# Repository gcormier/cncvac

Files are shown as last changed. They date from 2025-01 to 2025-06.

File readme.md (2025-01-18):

# cncvac
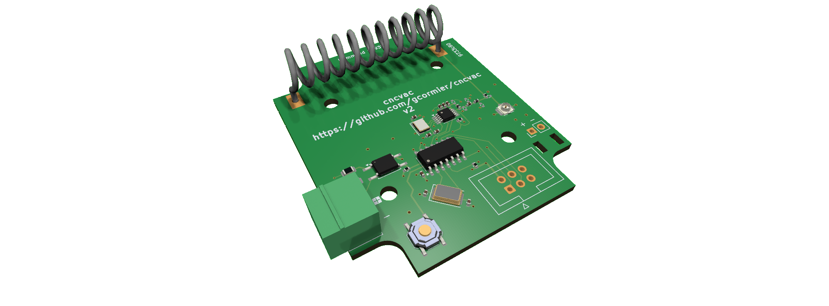
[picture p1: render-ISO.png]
Rendered ISO Image


This is a 433MHz ASK/FSK transmitter controlled by an ATTINY841.

It runs off regular AA/AAA batteries and can be used to control various devices like garage doors, gates, etc. The intent was to have it control my dust collection system in the shop which is using the iVac Pro system. The iVac Pro system is a great system but it is expensive and I wanted to have a cheaper alternative to control it, and the company did not offer a remote control that could be triggered from a logic signal. (They now sell one)

It has an opto-isolated input controlled by a 5-24V logic signal.

### Case
This fits in a [Hammond 1593P case](https://www.digikey.ca/en/products/detail/hammond-manufacturing/1593PBK/270098) and can use their [battery holder](https://www.digikey.ca/en/products/detail/hammond-manufacturing/BH3AAAW/3869833) as well.

### Power Consumption
#### Transmitting
1mV = 1uA
1-3mA while transmitting

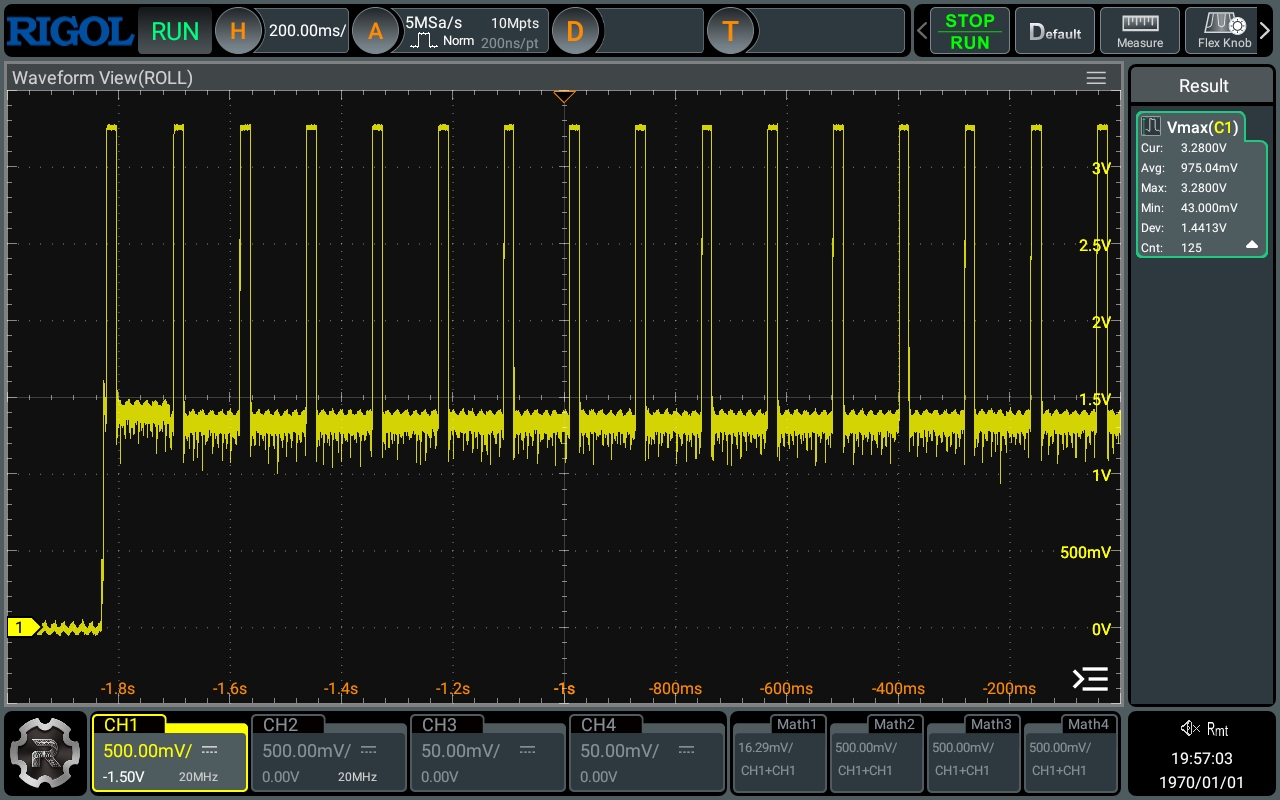
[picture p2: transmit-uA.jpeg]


#### Sleep/Idle
1mV = 1nA
Better than 1.2uA while sleeping
Based on the average capacity of two AA NiMH batteries, 2000mAh, this should last almost 200 years.
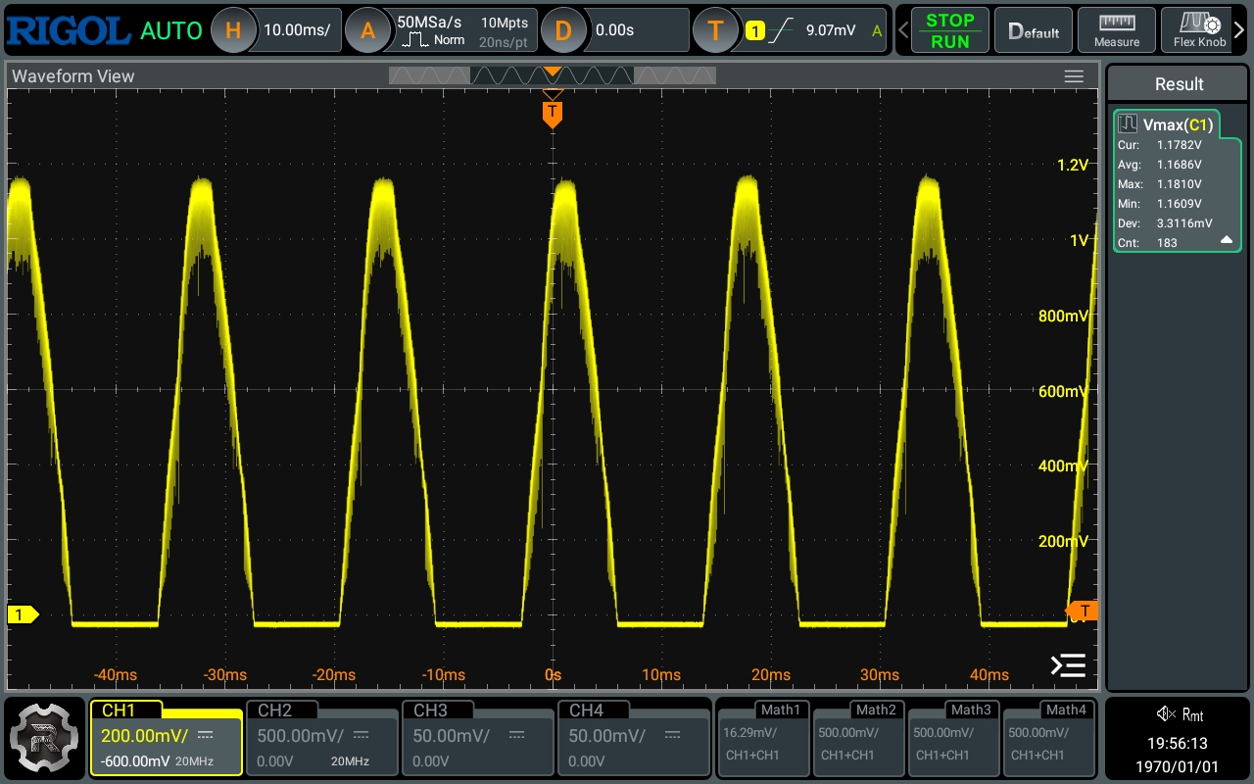
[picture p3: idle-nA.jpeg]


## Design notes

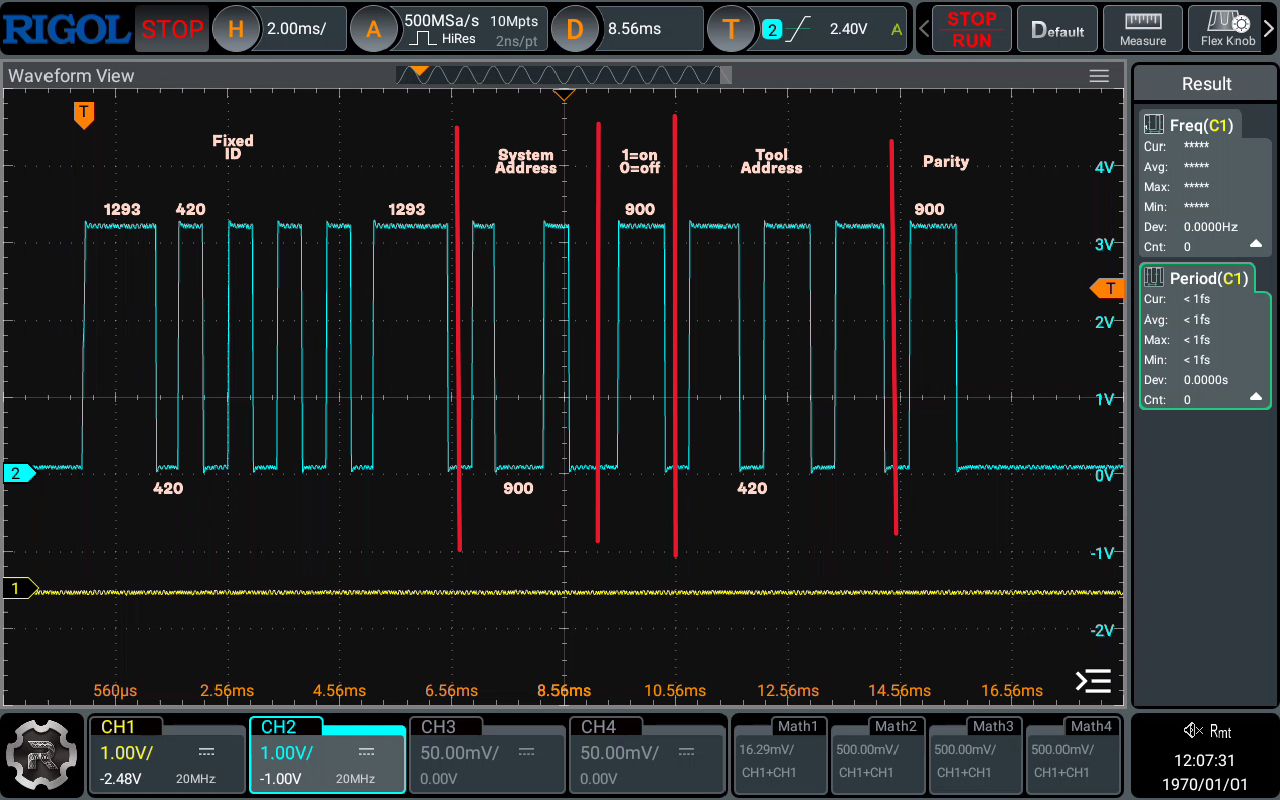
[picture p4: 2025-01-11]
code/captures/on_remote.png

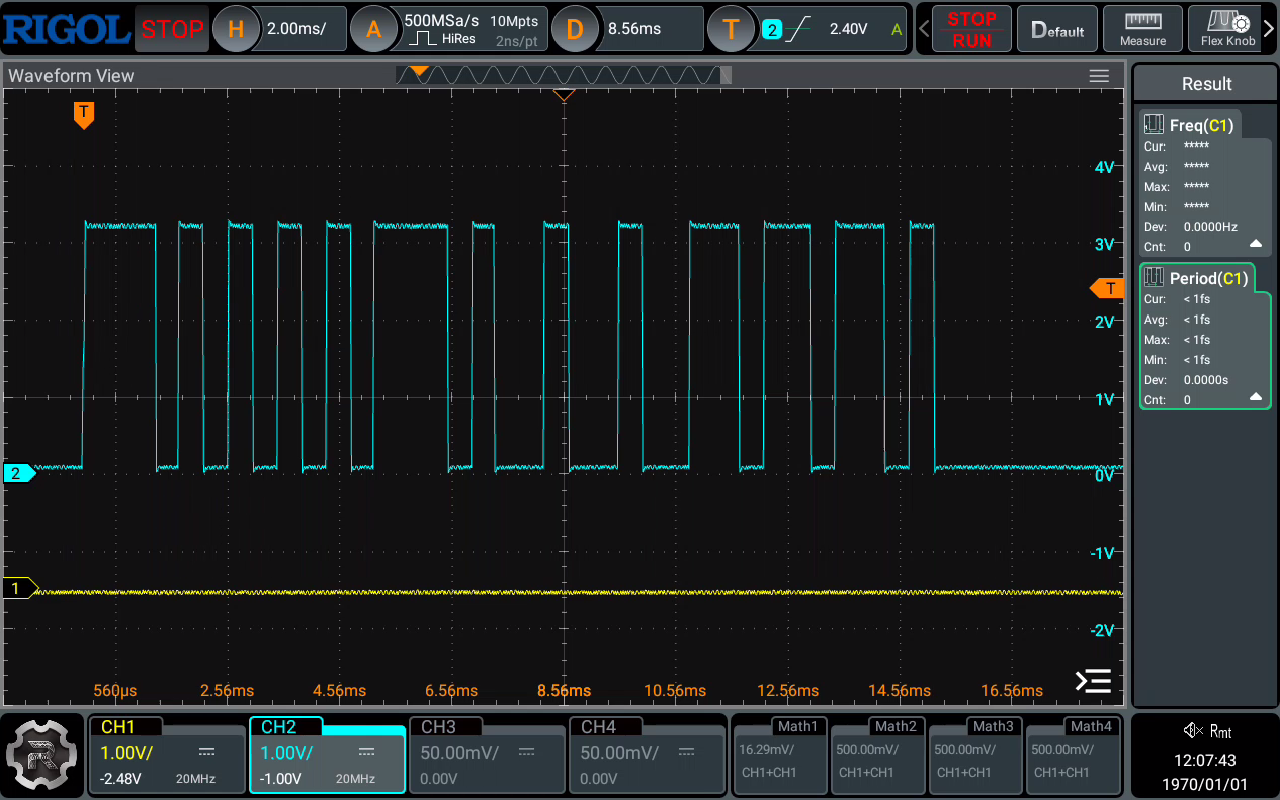
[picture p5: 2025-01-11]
code/captures/off_remote.png

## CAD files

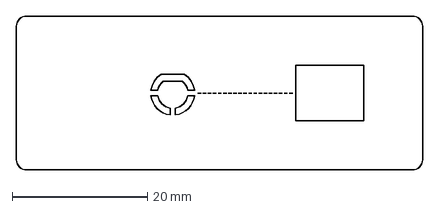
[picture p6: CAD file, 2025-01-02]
pcb/enclosurepanel/frontplate.dxf
60.0 x 22.7 mm

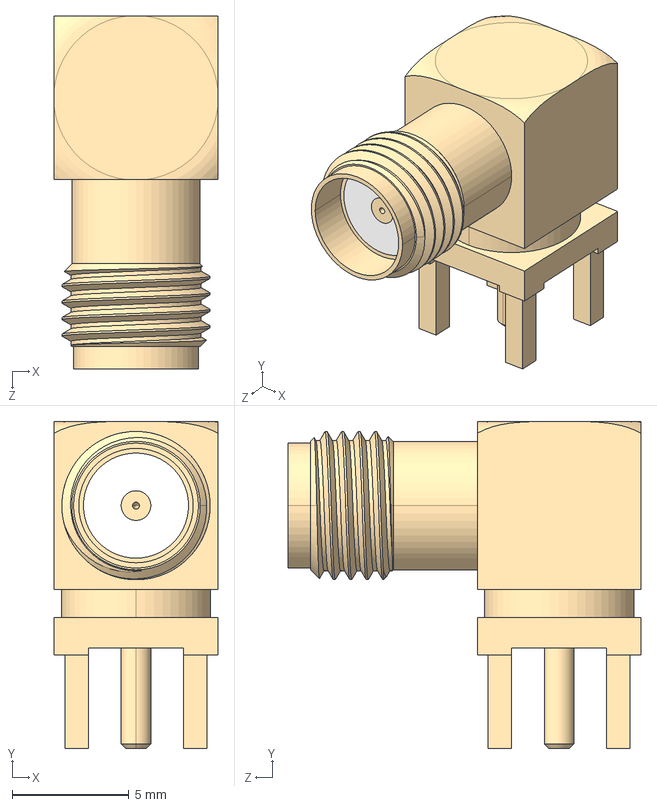
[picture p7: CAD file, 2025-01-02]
pcb/RFPC-SMA27.STEP
7.00 x 14.0 x 15.1 mm

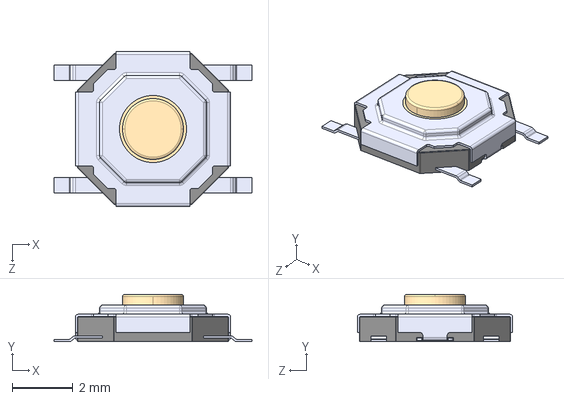
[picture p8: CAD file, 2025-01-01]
pcb/TS-1187A.STEP
6.50 x 1.55 x 5.10 mm

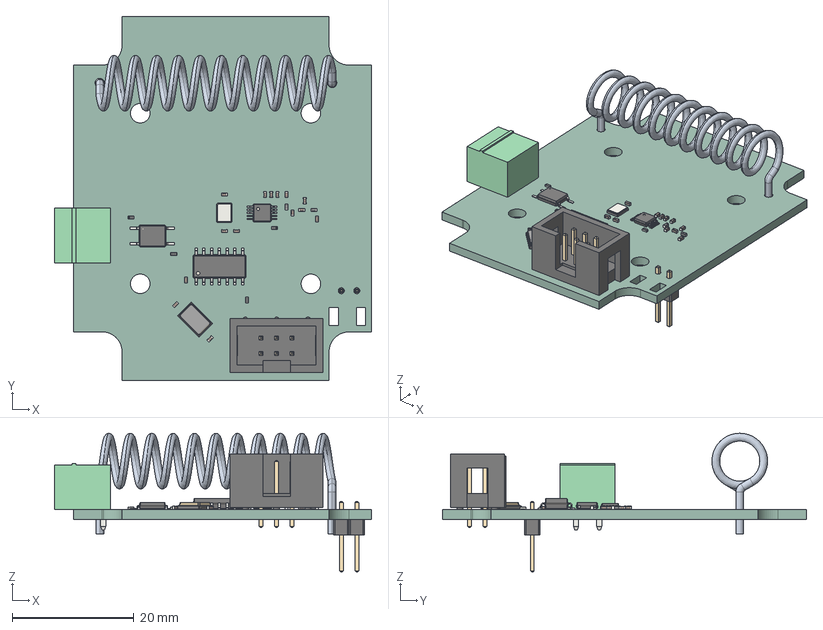
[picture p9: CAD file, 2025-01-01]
PCB/cncvac.step
52.0 x 59.7 x 22.7 mm
C_0402_1005Metric x 14
L_0402_1005Metric x 2
MSOP_10_3x3mm_P05mm
R_0402_1005Metric x 4
Crystal_SMD_3225-4Pin_3.2x2.5mm
Crystal_SMD_5032-2Pin_5.0x3.2mm
C-ANT-433-HETH
IDC_Header_2x03_P254mm_Vertical
MC_01x02_G_3_81mm
SO_4_44x36mm_P254mm
SOIC_14_39x87mm_P127mm
PinHeader_1x02_P254mm_Vertical
cncvac_PCB

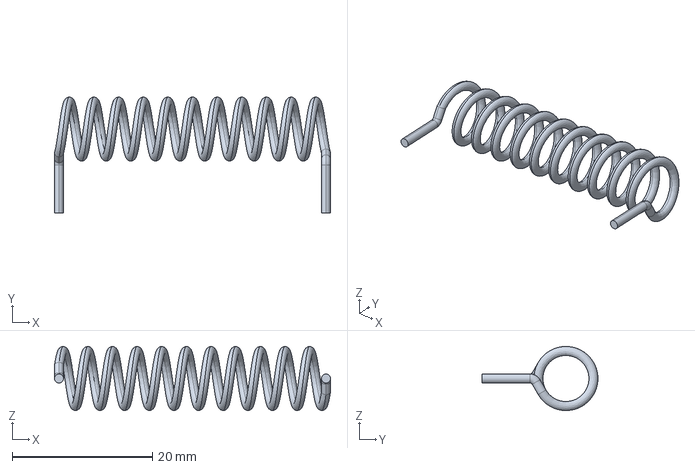
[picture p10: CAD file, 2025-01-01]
pcb/c-ant-433-heth-b-3d.stp
39.4 x 16.5 x 9.14 mm

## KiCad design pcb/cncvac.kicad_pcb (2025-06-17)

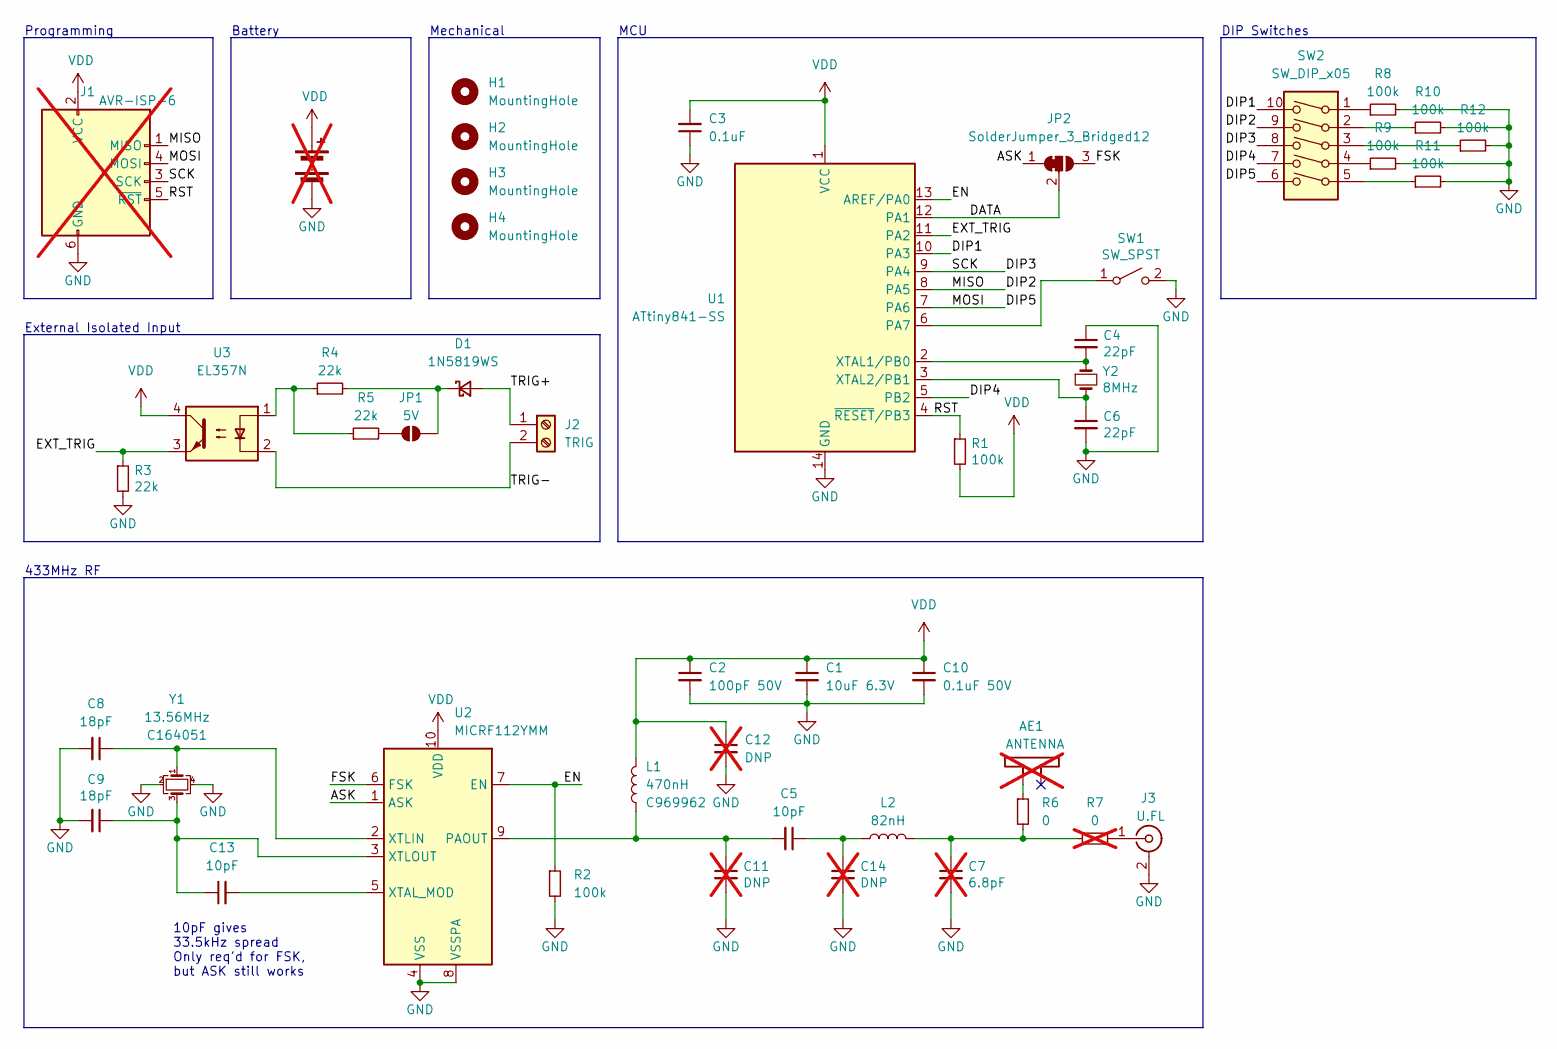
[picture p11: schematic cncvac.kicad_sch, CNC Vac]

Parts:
AE1: ANTENNA; ANT-433-HETH; not fitted
BT1: Battery; PinHeader_1x02_P2.54mm_Vertical; not fitted
C1: 10uF 6.3V; C_0402_1005Metric; LCSC C15525
C2: 100pF 50V; C_0402_1005Metric; LCSC C1546
C3: 0.1uF; C_0402_1005Metric; LCSC C307331
C4, C6: 22pF; C_0402_1005Metric; LCSC C1555
C5, C13: 10pF; C_0402_1005Metric; LCSC C32949
C7: 6.8pF; C_0402_1005Metric; not fitted
C8, C9: 18pF; C_0402_1005Metric; LCSC C1549
C10: 0.1uF 50V; C_0402_1005Metric; LCSC C307331
C11, C12, C14: DNP; C_0402_1005Metric; not fitted
D1: 1N5819WS; D_SOD-323; LCSC C191023
H1, H2, H3, H4: MountingHole; MountingHole_3.2mm_M3
J1: AVR-ISP-6; IDC-Header_2x03_P2.54mm_Vertical; not fitted
J2: TRIG; PhoenixContact_MC_1,5_2-G-3.81_1x02_P3.81mm_Horizontal; LCSC C8387
J3: U.FL; U.FL_Hirose_U.FL-R-SMT-1_Vertical; LCSC C5137195
JP1: 5V; SolderJumper-2_P1.3mm_Open_RoundedPad1.0x1.5mm
JP2: SolderJumper_3_Bridged12; SolderJumper-3_P1.3mm_Bridged12_RoundedPad1.0x1.5mm_NumberL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
L1: 470nH; L_0402_1005Metric; LCSC C969962
L2: 82nH; L_0402_1005Metric; LCSC C275301
R1, R2, R8, R9, R10, R11, R12: 100k; R_0402_1005Metric; LCSC C25741
R3, R4, R5: 22k; R_0805_2012Metric; LCSC C17560
R6: 0; R_0402_1005Metric; LCSC C17168
R7: 0; R_0402_1005Metric; LCSC C17168; not fitted
SW1: SW_SPST; SW_Push_1P1T_XKB_TS-1187A; LCSC C318884
SW2: SW_DIP_x05; SW_DIP_SPSTx05_Slide_9.78x14.88mm_W7.62mm_P2.54mm; LCSC C129061
U1: ATtiny841-SS; SOIC-14_3.9x8.7mm_P1.27mm; LCSC C614879
U2: MICRF112YMM; MSOP-10_3x3mm_P0.5mm; LCSC C481379
U3: EL357N; SO-4_4.4x3.6mm_P2.54mm; LCSC C42381015
Y1: 13.56MHz; Crystal_SMD_3225-4Pin_3.2x2.5mm; LCSC C164051
Y2: 8MHz; Crystal_SMD_5032-2Pin_5.0x3.2mm; LCSC C115962

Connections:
/ASK: JP2.1 (A), U2.1 (ASK)
/DATA: JP2.2 (C), U1.12 (PA1)
/DIP1: SW2.10, U1.10 (PA3)
/DIP2: J1.1 (MISO), SW2.9, U1.8 (PA5)
/DIP3: J1.3 (SCK), SW2.8, U1.9 (PA4)
/DIP4: SW2.7, U1.5 (PB2)
/DIP5: J1.4 (MOSI), SW2.6, U1.7 (PA6)
/EN: R2.1, U1.13 (AREF/PA0), U2.7 (EN)
/EXT_TRIG: R3.1, U1.11 (PA2), U3.3
/FSK: JP2.3 (B), U2.6 (FSK)
/RST: J1.5 (~RST), R1.1, U1.4 (~RESET/PB3)
/TRIG+: D1.2 (A), J2.1
/TRIG-: J2.2, U3.2
GND: BT1.2 (-), C1.2, C2.2, C3.1, C4.1, C6.2, C7.2, C8.2, C9.2, C10.2, C11.2, C12.2, C14.2, J1.6 (GND), J3.2 (Ext), R2.2, R3.2, R8.2, R9.2, R10.2, R11.2, R12.2, SW1.2 (B), U1.14 (GND), U2.4 (VSS), U2.8 (VSSPA), Y1.2, Y1.4
unnamed: AE1.2, R6.1
unnamed: C7.1, L2.2, R6.2, R7.1
unnamed: C5.1, C14.1, L2.1
unnamed: D1.1 (K), JP1.2 (B), R4.2
unnamed: J3.1 (In), R7.2
unnamed: JP1.1 (A), R5.2
unnamed: R4.1, R5.1, U3.1
unnamed: R8.1, SW2.1
unnamed: R9.1, SW2.4
unnamed: R10.1, SW2.2
unnamed: R11.1, SW2.5
unnamed: R12.1, SW2.3
unnamed: SW1.1 (A), U1.6 (PA7)
unnamed: C4.2, U1.2 (XTAL1/PB0), Y2.1
unnamed: C6.1, U1.3 (XTAL2/PB1), Y2.2
unnamed: C5.2, C11.1, L1.1, U2.9 (PAOUT)
unnamed: C13.2, U2.5 (XTAL_MOD)
unnamed: C8.1, U2.2 (XTLIN), Y1.1
unnamed: C9.1, C13.1, U2.3 (XTLOUT), Y1.3
VDD: BT1.1 (+), C1.1, C2.1, C3.2, C10.1, C12.1, J1.2 (VCC), L1.2, R1.2, U1.1 (VCC), U2.10 (VDD), U3.4

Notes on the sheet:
MCU
10pF gives 33.5kHz spread Only req'd for FSK, but ASK still works
Mechanical
External Isolated Input
Programming
Battery
433MHz RF
DIP Switches

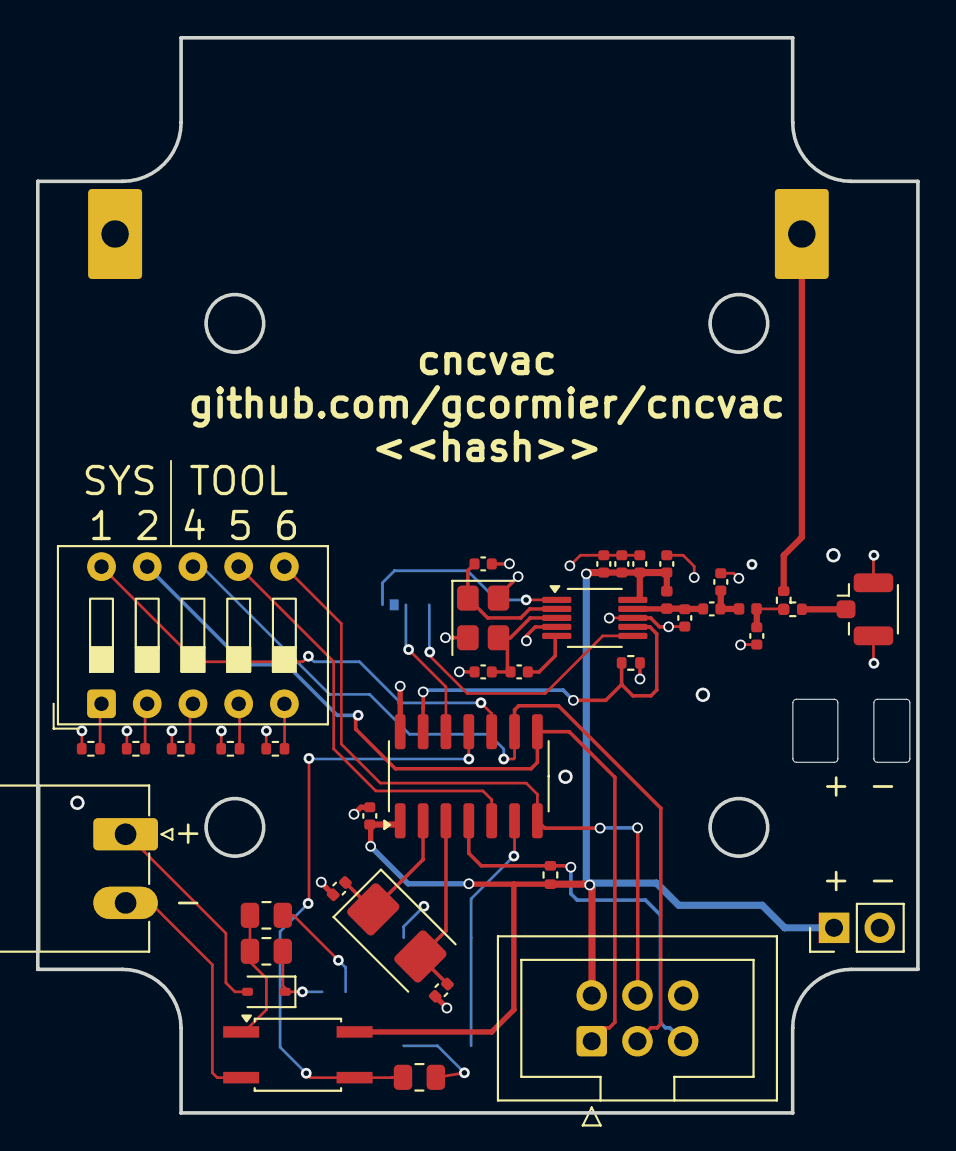
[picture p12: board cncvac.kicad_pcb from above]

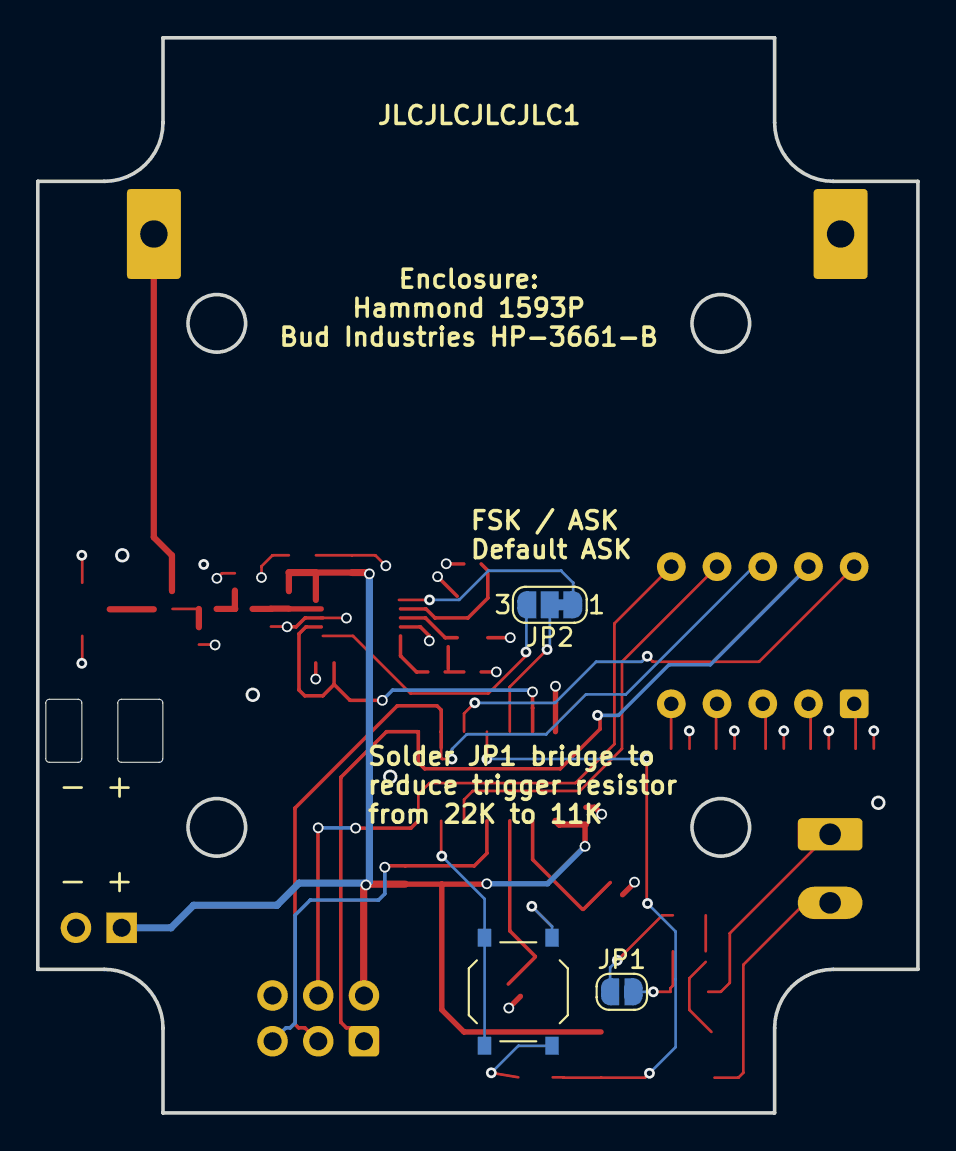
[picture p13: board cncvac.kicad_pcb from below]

Board: 4 copper layers, 48.9 x 59.7 mm, 47 parts (3 on the bottom side), 34 nets.

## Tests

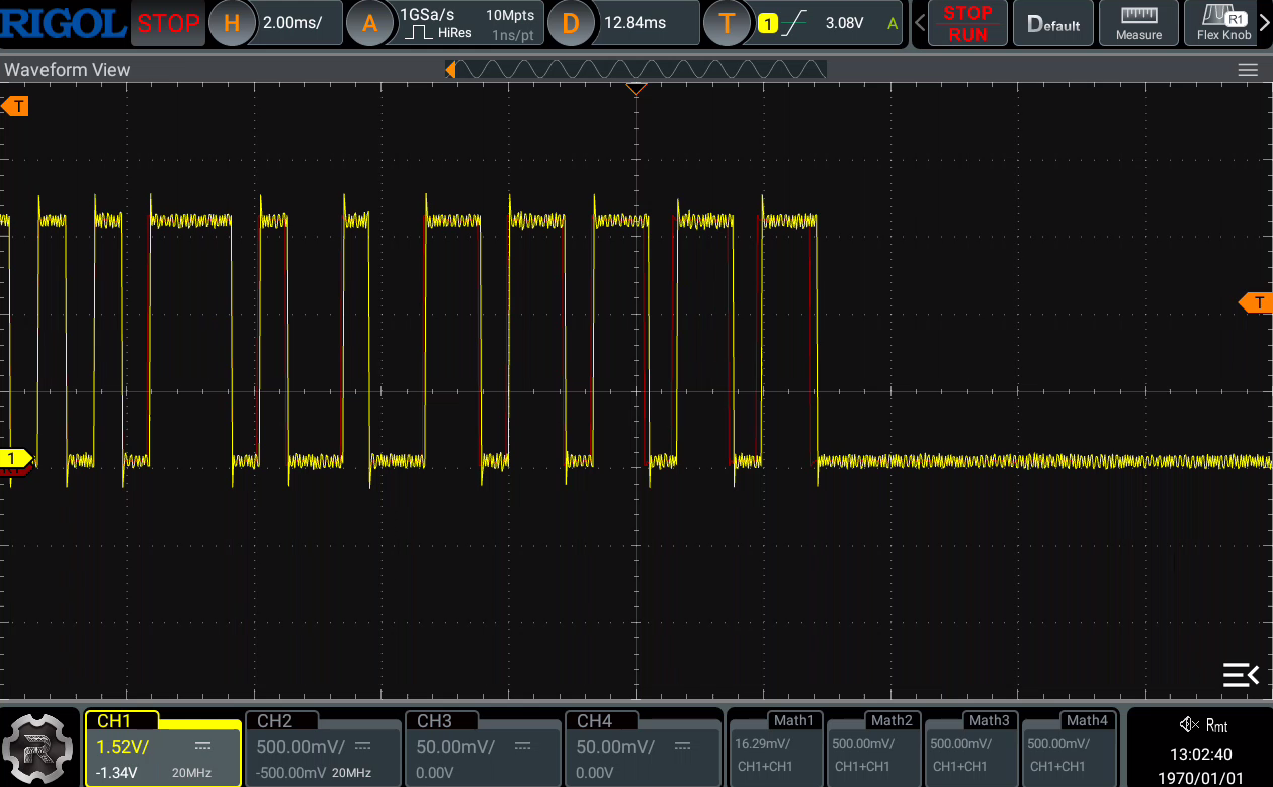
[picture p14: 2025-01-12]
code/captures/tuning.png

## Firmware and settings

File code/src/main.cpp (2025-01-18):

#include <avr/wdt.h>
#include <avr/power.h>
#include <avr/sleep.h>
#include <Arduino.h>
#include "cncvac.h"

///// Pinout https://github.com/SpenceKonde/ATTinyCore/blob/v2.0.0-devThis-is-the-head-submit-PRs-against-this/avr/extras/Pinout_x41.jpg
// Misery.
// PA0 or PORTA0 is defined by shitty platformio Atmel libraries and is broken
// A8 is defined by tinyavr and uses the clockwise/counterclockwise mapping. but it seems to break after a bit.
// Use raw numbers and test each output to make sure it works.

#define PIN_EN 0     // PA0, Pin 13, Arduino 10
#define PIN_FSK 1  // PA1, Pin 12, Arduino 9
#define PIN_ASK 2    // PA2, Pin 11, Arduino 8
#define PIN_BUTTON 7 // PA7, Pin 6, PCINT7
#define PIN_EXT_TRIG 3
#define PIN_MISC 8


#define ENHIGH (bitSet(PORTA, PIN_EN))
#define ENLOW (bitClear(PORTA, PIN_EN))

#define ASKHIGH (bitSet(PORTA, PIN_ASK))
#define ASKLOW (bitClear(PORTA, PIN_ASK))

#define FSKHIGH (bitSet(PORTA, PIN_FSK))
#define FSKLOW (bitClear(PORTA, PIN_FSK))

#define PACKET_DELAY 100 // Milliseconds inter-packet period

#define SHORTPACKETUS 410  // Short packet duration in uS
#define LONGPACKETUS 860   // Long packet duration in uS
#define TOTALPACKETUS 1250 // Total packet duration in uS for fix-bit width PWM

#define WEIRDLONGPACKETUS 1220 // Fixed preamble duration in uS
#define WEIRDSHORTPACKETUS 820 // Longer lows during system address
#define BREAKPACKETUS 2000     // Break between packets in uS
#define TWEAK 23               // Typically this will be your period (eg 50kHz interrupt, 20uS)
                               // but you can fine tune as needed

#define PACKET_RETRANSMIT 12 // How many times to resend the same packet?
#define PACKET_SIZE 13       // We only actually want 13 bits here

/*
             xxxx xx98 7654 3210
Bit position 1234 5678 1234 5678
             IIII IISS CTTT P000
*/

#define BIT_SYS1 9
#define BIT_SYS0 8
#define BIT_ONOFF 7
#define BIT_TOOL2 6
#define BIT_TOOL1 5
#define BIT_TOOL0 4
#define BIT_PARITY 3
#define FIXED 33792 // This is the fixed preamble. Do not change.

// This is where you define your on/off packet. You really need to only change the TOOL bits and the SYS bits.
// Even number of 1's? Set the bit parity flag.
const unsigned short onPacket = FIXED | (1 << BIT_ONOFF) | (1 << BIT_TOOL2) | (1 << BIT_TOOL1) | (1 << BIT_TOOL0) | (1 << BIT_PARITY);
const unsigned short offPacket = FIXED | (1 << BIT_TOOL2) | (1 << BIT_TOOL1) | (1 << BIT_TOOL0);

volatile unsigned short currentPacket = onPacket;
volatile unsigned int currentBit; // which bit in that packet is next

volatile bool transmitting = false; // indicates if transmitting a packet

volatile unsigned int wakeupReason = 0; // 1 = button, 2 = aux

volatile unsigned int tickCounter = 0; // count the number of interrupts, so we can determine how long to pulse for
volatile unsigned int sendLow = 0;     // Tell us to send the low signal
volatile unsigned int transmitCount;   // Countdown our transmit resends
volatile unsigned int previousBit = 0;

// setup functions

void calculateParity(unsigned short data)
{
  bool parityVal = false;
  for (int bit = 0; bit < 12; bit++)
  {
    // Calculate the parity of the first 12 bits in data, and store it in the 13th bit
    if (data & (1 << bit))
      parityVal = !parityVal;
  }
  data |= parityVal << 12;
}

// 50khz Interrupt for an 4MHz clock
// 50khz = 20uS
void setupInterrupt4()
{
  noInterrupts();
  // Clear registers
  TCCR1A = 0;
  TCCR1B = 0;
  TCNT1 = 0;

  OCR1A = 79;

  // CTC
  TCCR1B |= (1 << WGM12);

  // Prescaler 1
  TCCR1B |= (1 << CS00);

  // Output Compare Match A Interrupt Enable
  TIMSK1 |= (1 << OCIE1A);

  // button interrupt
  PCMSK0 |= (1 << PIN_BUTTON);

  // Opto interrupt
  PCMSK0 |= (1 << PIN_EXT_TRIG);
  GIMSK |= (1 << PCIE0);

  interrupts();
}

// 10khz Interrupt for an 8MHz clock
void setupInterrupt8()
{
  noInterrupts();
  // Clear registers
  TCCR1A = 0;
  TCCR1B = 0;
  TCNT1 = 0;

  // 10000 Hz (8000000/((99+1)*8))
  OCR1A = 99;
  // CTC
  TCCR1B |= (1 << WGM12);
  // Prescaler 8
  TCCR1B |= (1 << CS11);
  // Output Compare Match A Interrupt Enable
  TIMSK1 |= (1 << OCIE1A);

  // button interrupt
  PCMSK0 |= (1 << PIN_BUTTON);
  // Opto interrupt
  PCMSK0 |= (1 << PIN_EXT_TRIG);
  GIMSK |= (1 << PCIE0);

  interrupts();
}

// 10khz Interrupt for a 16MHz clock
void setupInterrupt16()
{
  noInterrupts();
  // Clear registers
  TCCR1A = 0;
  TCCR1B = 0;
  TCNT1 = 0;

  // 10000 Hz (16000000/((24+1)*64))
  OCR1A = 24;
  // CTC
  TCCR1B |= (1 << WGM12);
  // Prescaler 64
  TCCR1B |= (1 << CS11) | (1 << CS10);
  // Output Compare Match A Interrupt Enable
  TIMSK1 |= (1 << OCIE1A);

  // button interrupt
  PCMSK0 |= (1 << PIN_BUTTON);
  // Opto interrupt
  PCMSK0 |= (1 << PIN_EXT_TRIG);
  GIMSK |= (1 << PCIE0);

  interrupts();
}

void setup()
{
  // We have an 8MHz, and we have CKDIV8 fuse set, so we are running at 1MHz
  // This is to allow a safe startup with unknown power conditions. Then, we immediately
  // switch the scaler to 4MHz for a bit better performance, but we can still operate
  // down to 1.8V (datasheet page 238)
  cli();
  CLKPR = (1 << CLKPS0); // Set prescaler to divide by 2 (8 MHz / 2 = 4 MHz)
  sei();                 // Re-enable interrupts
  for (byte i = 0; i < 13; i++)
    pinMode(i, INPUT);

  // disable ADC + other stuff that uses power
  ADCSRA = 0;
  power_spi_disable();
  power_usart0_disable();
  power_usart1_disable();
  power_timer2_disable();
  power_twi_disable();
  // find more in power.h

  pinMode(PIN_EN, OUTPUT);
  pinMode(PIN_FSK, OUTPUT);
  pinMode(PIN_ASK, OUTPUT);
  pinMode(PIN_BUTTON, INPUT_PULLUP);
  pinMode(PIN_EXT_TRIG, INPUT);

#if F_CPU == 16000000L
  setupInterrupt16();
#elif F_CPU == 8000000L
  setupInterrupt8();
#elif F_CPU == 4000000L
  setupInterrupt4();
#else
#error Cannot set interrupt based on current clock frequency!
#endif
  disableTX();
}

// runtime functions

ISR(TIMER1_COMPA_vect)
{
  if (transmitting)
  {
    if (tickCounter > 0) // If we need to keep this signal high for longer, keep going
    {
      tickCounter--;
      return;
    }
    else if (tickCounter == 0 && sendLow == 1)
    {
      sendLow = 0;
      ASKLOW;
      if (currentBit < 6) // Preamble
        tickCounter = SHORTPACKETUS / TWEAK;
      else // We are done the preamble, go to fixed width
      {
        previousBit = currentPacket & (0x8000 >> (currentBit - 1));
        // If the previous bit (the one we are currently transmitting) is a 1, we need to send a shorter low pulse then a 0 bit.
        if (previousBit)
          tickCounter = (TOTALPACKETUS - LONGPACKETUS) / TWEAK;
        else
          tickCounter = (TOTALPACKETUS - SHORTPACKETUS) / TWEAK;
      }

      return;
    }

    if (currentBit >= PACKET_SIZE) // end of packet
    {
      disableTX();
      return;
    }

    // read off bits in bigendian order
    if (currentPacket & (0x8000 >> currentBit))
    {
      // We need to send a 1 which means be high for LONGPACKETUS, then be low for SHORTPACKETUS
      ASKHIGH;
      // If we are doing the preamble, then we use the weird longer length
      if (currentBit < 6)
        tickCounter = WEIRDLONGPACKETUS / TWEAK;
      else
        tickCounter = LONGPACKETUS / TWEAK;

      sendLow = 1;
    }
    else
    {
      ASKHIGH;
      tickCounter = SHORTPACKETUS / TWEAK;
      sendLow = 1;
    }

    currentBit++;
  }
}

// button interrupt is setup by setupInterrupt8()
ISR(PCINT0_vect)
{
  delay(50);
  // could use a +300ms debounce here, but its not critcal if we transmit packets twice...
  if (digitalRead(PIN_BUTTON) == LOW)
    wakeupReason = 1;
  else if (digitalRead(PIN_EXT_TRIG) == LOW)
  {
    //digitalWrite(PIN_MISC, LOW);
    wakeupReason = 2;
    currentPacket = offPacket;
  }
  else if (digitalRead(PIN_EXT_TRIG) == HIGH)
  {
    //digitalWrite(PIN_MISC, HIGH);
    wakeupReason = 2;
    currentPacket = onPacket;
  }
}

// sleep until an WDT/button interrupt fires
void sleepyTime()
{
  // Just in case
  disableTX();

  set_sleep_mode(SLEEP_MODE_PWR_DOWN);

  sleep_enable();
  sleep_mode();
  sleep_disable();
}

// queue up and prepare to send a packet
void sendPacket(unsigned short whichPacket)
{
  currentPacket = whichPacket;
  currentBit = 0;
  enableTX();
}

// warm-up transmitter and enable bit-period interrupt
void enableTX()
{
  FSKLOW;
  ASKLOW;
  ENHIGH;

  delayMicroseconds(50); // warm-up time
  transmitting = true;
  power_timer1_enable();
}

// disable transmitter and disable bit-period interrupt
void disableTX()
{
  FSKLOW;
  ENLOW;
  ASKLOW;
  transmitting = false;
  power_timer1_disable();
}

void loop()
{
  if (wakeupReason > 0)
  {
    for (transmitCount = 0; transmitCount < PACKET_RETRANSMIT; transmitCount++)
    {
      sendPacket(currentPacket);
      delay(PACKET_DELAY);
    }
    // reset to wait for next tx
    wakeupReason = 0;

    // Swap packets in case it was the button used for debugging.
    // Otherwise the aux input will set the currentPacket based on high/low status of aux input
    if (currentPacket == onPacket)
      currentPacket = offPacket;
    else
      currentPacket = onPacket;
  }

  sleepyTime();
}

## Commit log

2025-01-02 add via for rf test
    [cncvac.kicad_pcb]
2025-01-12 fixed width pwm
2025-01-13 shift the antenna opening in the panel slightly
    [cncvac.kicad_pcb, cncvac.kicad_sch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]
2025-01-16 pin nightmare for interrupts
2025-01-17 Add protection diode to opto, increase pulldown strength
    [cncvac.kicad_pcb, cncvac.kicad_sch, panel1.kicad_pcb]
2025-06-15 fix silk
    [cncvac.kicad_pcb]
2025-06-15 update part number for opto
    [cncvac.kicad_sch]
2025-06-17 fix pn for opto
    [cncvac.kicad_pcb, cncvac.kicad_sch]
